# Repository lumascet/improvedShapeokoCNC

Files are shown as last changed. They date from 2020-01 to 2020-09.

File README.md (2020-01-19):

# Improved Shapeoko CNC Mill

:warning: the schematics file is incomplete and has errors which are listed in PATCHNOTES.txt :warning:

This repository contains the config file for g2core as well as the shield schematics for arduino due.

See https://github.com/synthetos/g2 for the g2core project.

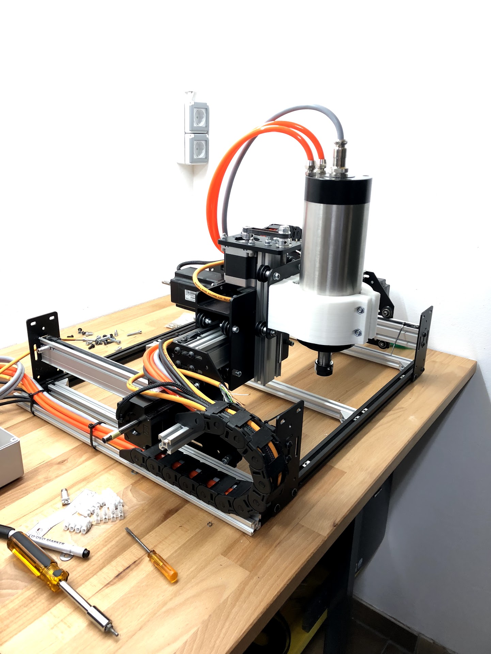
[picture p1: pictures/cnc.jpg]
cnc

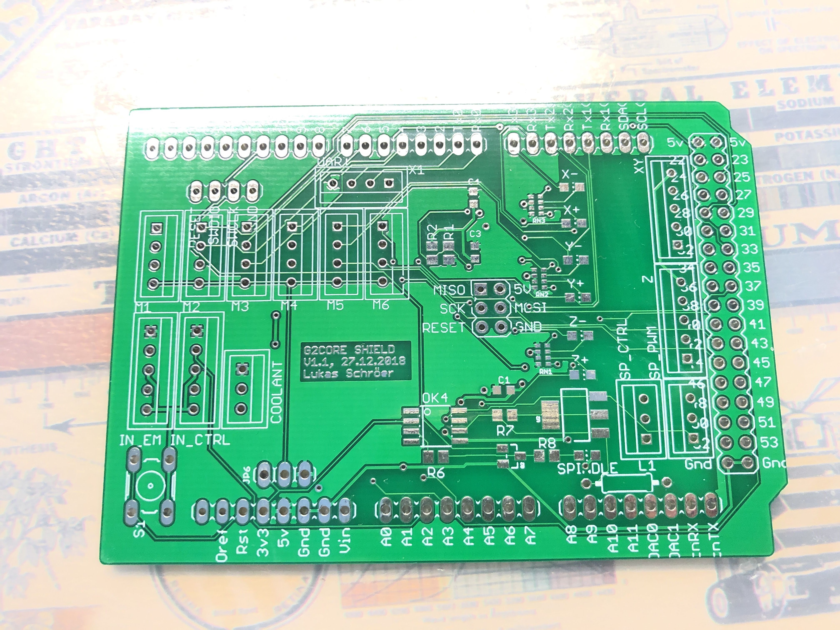
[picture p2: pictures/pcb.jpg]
pcb

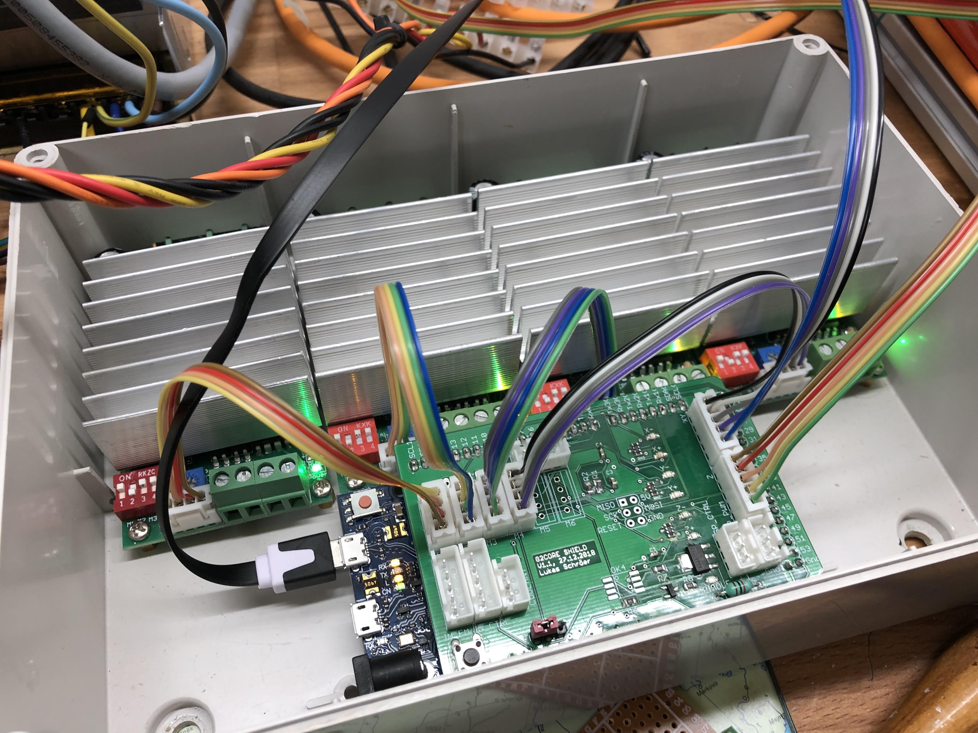
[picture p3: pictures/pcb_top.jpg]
pcb_t

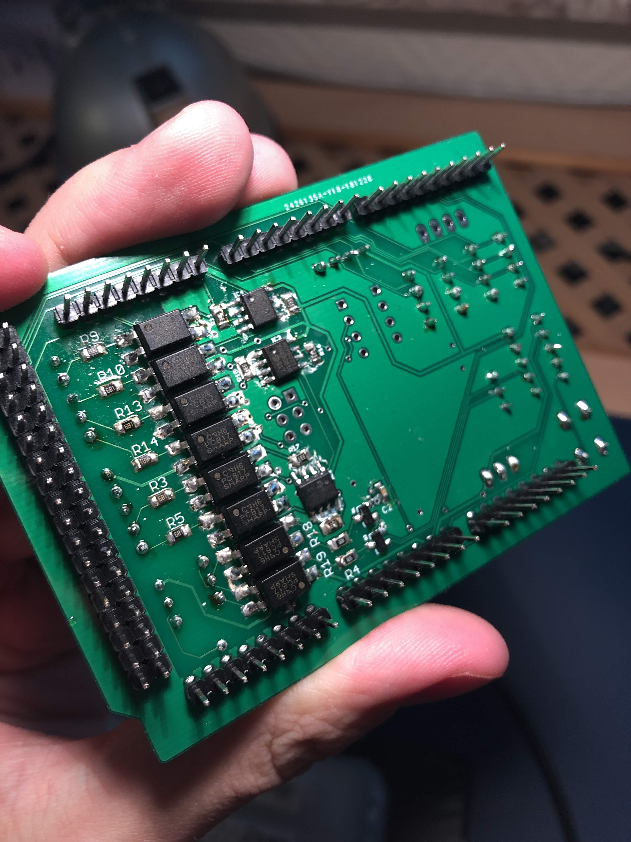
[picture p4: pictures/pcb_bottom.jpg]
pcb_b


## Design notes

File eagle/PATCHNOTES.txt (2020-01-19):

-higher series resistor for optoc. -> powertarget
-after optoc. 3v3 logic -> arduino due not 5V tolerant
-inverting z- axis
-higher series resistor for spindle pwm / otherwise pulse 20mA directly --> failed due to current not possible, modified to 0-5V 10kHz pwm
-switched spindle control @optoc. signals because active low

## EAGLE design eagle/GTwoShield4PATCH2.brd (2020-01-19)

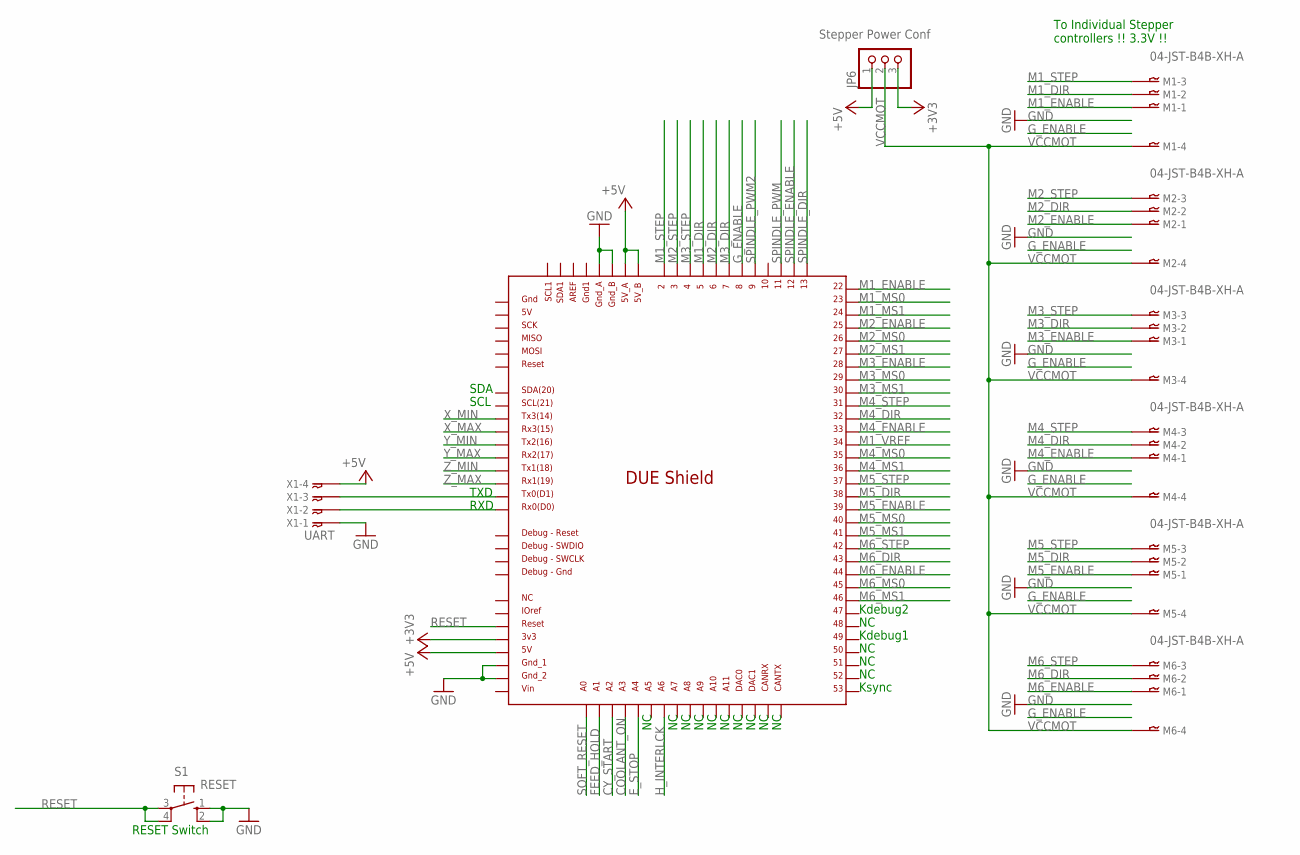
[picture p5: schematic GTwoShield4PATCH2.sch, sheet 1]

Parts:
JP6: Stepper Power Conf; 1X03
M1, M2, M3, M4, M5, M6: 04-JST-B4B-XH-A; B4B-XH
S1: RESET; B3F-10XX
U$1: DUE(NORMAL)
X1: UART; B4B-XH

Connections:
+3V3: JP6.3, U$1.3V3; also elsewhere on the board
+5V: JP6.1, U$1.5V, U$1.5V_A, U$1.5V_B, X1.P$4; also elsewhere on the board
COOLANT_ON: U$1.A3; also elsewhere on the board
CY_START: U$1.A2; also elsewhere on the board
E_STOP: U$1.A4; also elsewhere on the board
FEED_HOLD: U$1.A1; also elsewhere on the board
GND: S1.1 (S), S1.2 (S1), U$1.GND_1, U$1.GND_2, U$1.GND_A, U$1.GND_B, X1.P$1; also elsewhere on the board
G_ENABLE: U$1.8
H_INTERLCK: U$1.A6
M1_DIR: M1.P$2, U$1.5
M1_ENABLE: M1.P$1, U$1.22
M1_MS0: U$1.23
M1_MS1: U$1.24
M1_STEP: M1.P$3, U$1.2
M1_VREF: U$1.34
M2_DIR: M2.P$2, U$1.6
M2_ENABLE: M2.P$1, U$1.25
M2_MS0: U$1.26
M2_MS1: U$1.27
M2_STEP: M2.P$3, U$1.3
M3_DIR: M3.P$2, U$1.7
M3_ENABLE: M3.P$1, U$1.28
M3_MS0: U$1.29
M3_MS1: U$1.30
M3_STEP: M3.P$3, U$1.4
M4_DIR: M4.P$2, U$1.32
M4_ENABLE: M4.P$1, U$1.33
M4_MS0: U$1.35
M4_MS1: U$1.36
M4_STEP: M4.P$3, U$1.31
M5_DIR: M5.P$2, U$1.38
M5_ENABLE: M5.P$1, U$1.39
M5_MS0: U$1.40
M5_MS1: U$1.41
M5_STEP: M5.P$3, U$1.37
M6_DIR: M6.P$2, U$1.43
M6_ENABLE: M6.P$1, U$1.44
M6_MS0: U$1.45
M6_MS1: U$1.46
M6_STEP: M6.P$3, U$1.42
unnamed: U$1.TX0, X1.P$3
unnamed: U$1.RX0, X1.P$2
RESET: S1.3, S1.4 (P1), U$1.RESET
SOFT_RESET: U$1.A0; also elsewhere on the board
SPINDLE_DIR: U$1.13; also elsewhere on the board
SPINDLE_ENABLE: U$1.12; also elsewhere on the board
SPINDLE_PWM: U$1.11; also elsewhere on the board
SPINDLE_PWM2: U$1.9
VCCMOT: JP6.2, M1.P$4, M2.P$4, M3.P$4, M4.P$4, M5.P$4, M6.P$4
X_MAX: U$1.RX3; also elsewhere on the board
X_MIN: U$1.TX3; also elsewhere on the board
Y_MAX: U$1.RX2; also elsewhere on the board
Y_MIN: U$1.TX2; also elsewhere on the board
Z_MAX: U$1.RX1; also elsewhere on the board
Z_MIN: U$1.TX1; also elsewhere on the board

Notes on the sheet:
Kdebug2
Kdebug1
Ksync
SDA
SCL
TXD
RXD
To Individual Stepper controllers !! 3.3V !!
RESET Switch

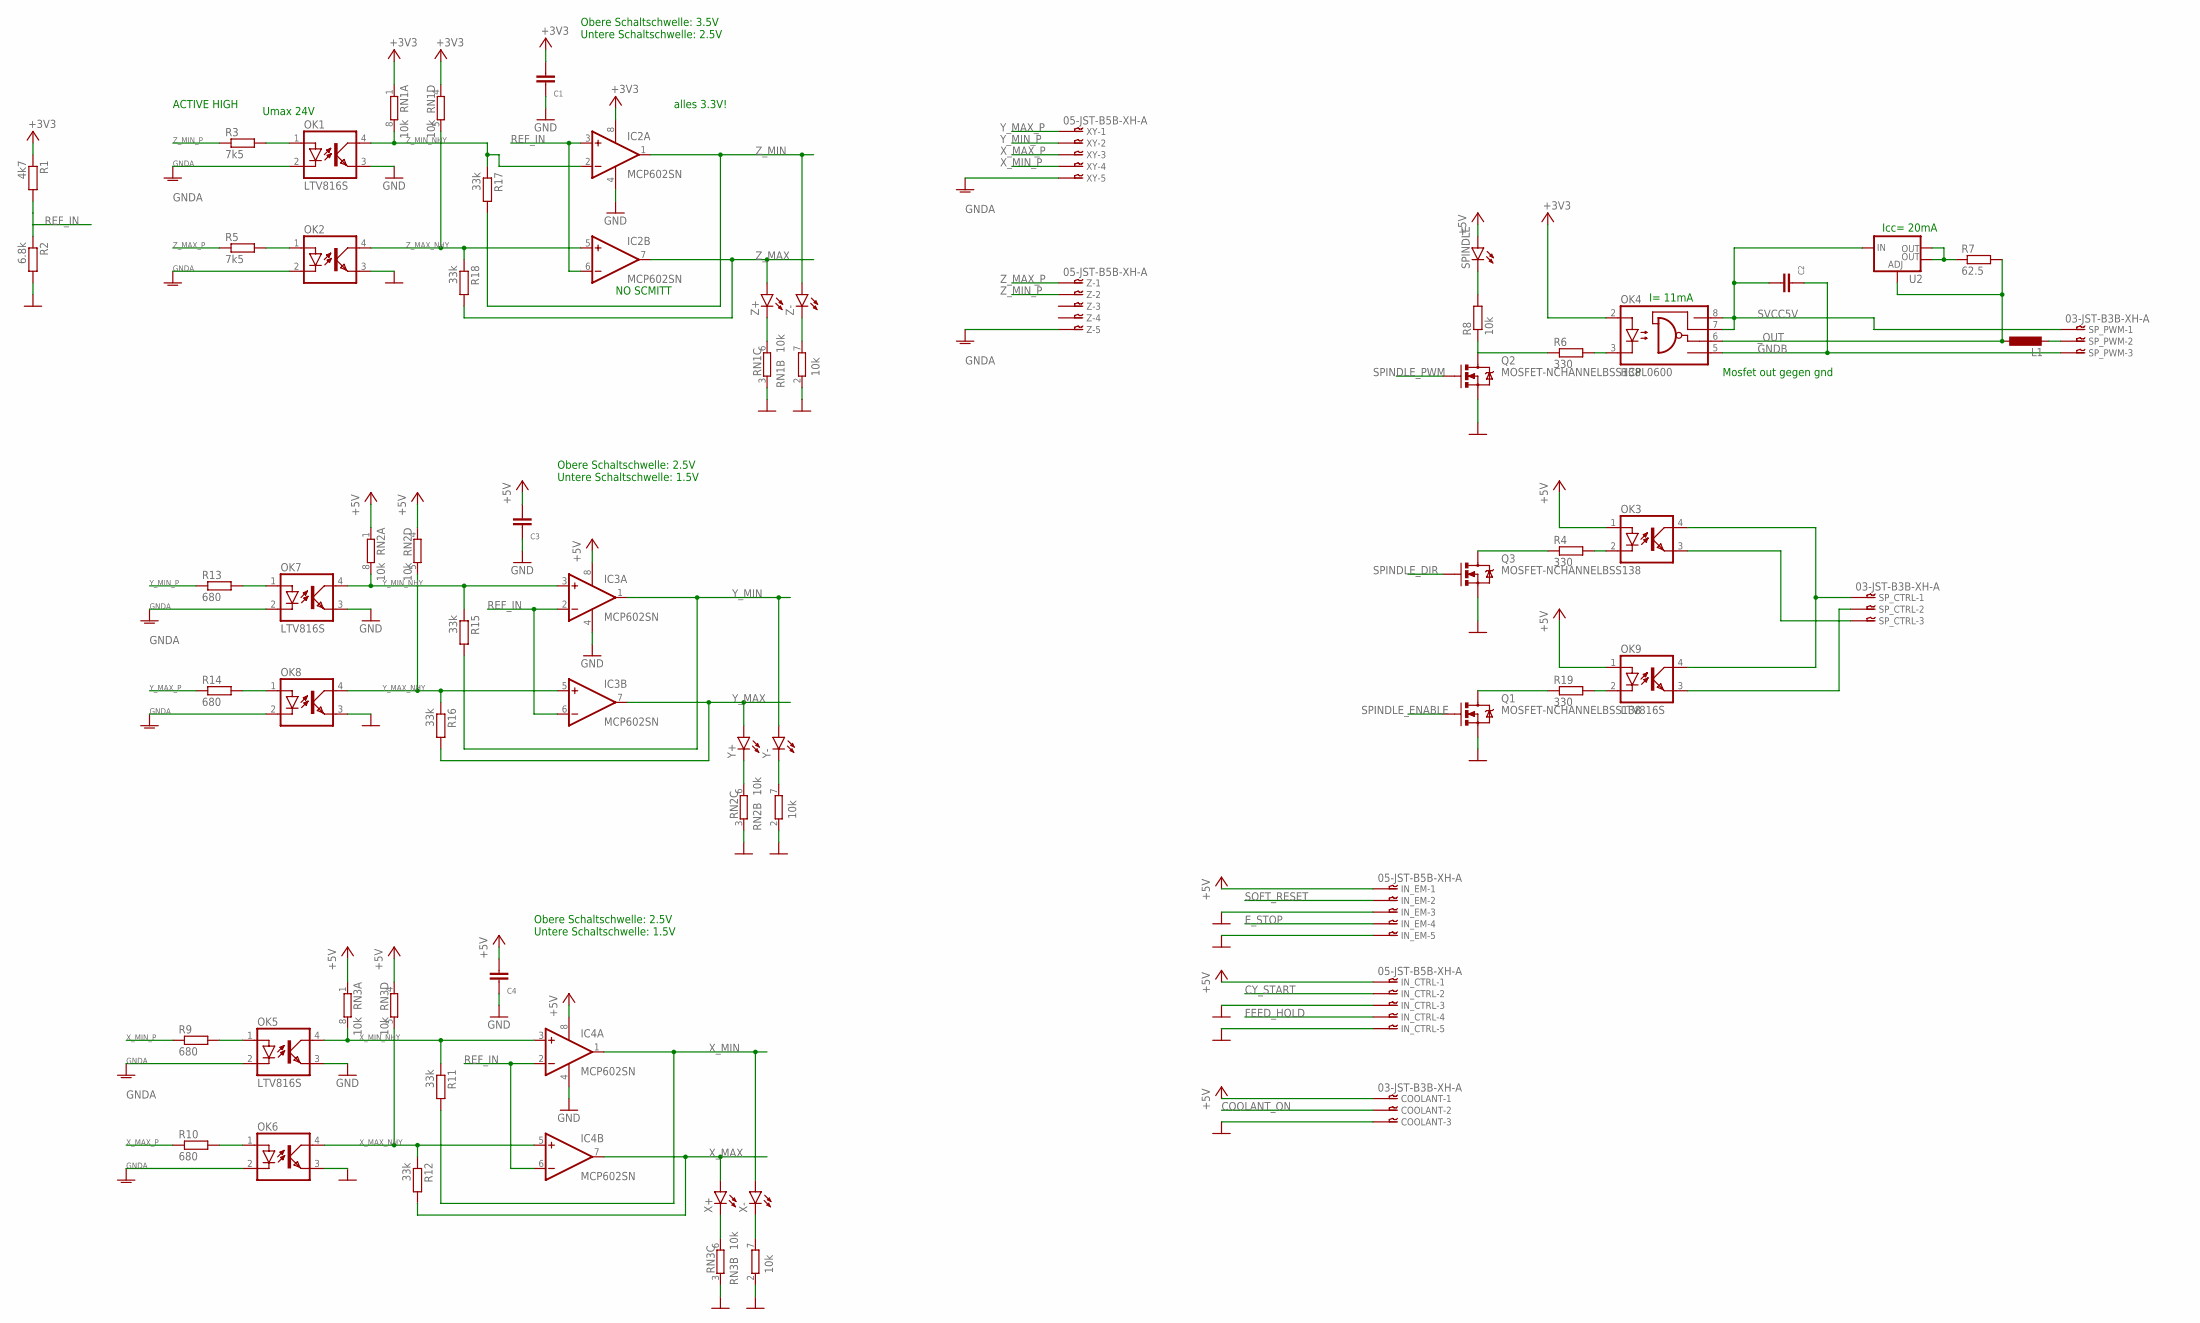
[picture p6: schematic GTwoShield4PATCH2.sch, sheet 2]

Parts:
C1, C2, C3, C4: 100nf; C0603K
COOLANT: 03-JST-B3B-XH-A; B3B-XH
IC2, IC3, IC4: MCP602SN; SO08
IN_CTRL: 05-JST-B5B-XH-A; B5B-XH
IN_EM: 05-JST-B5B-XH-A; B5B-XH
L1: L-EU0207/10; 0207/10
OK1, OK2, OK3, OK5, OK6, OK7, OK8, OK9: LTV816S; DIL4-SMD
OK4: HCPL0600; SOIC08
Q1, Q2, Q3: MOSFET-NCHANNELBSS138; SOT23
R1: 4k7; R0805
R2: 6.8k; R0805
R3, R5: 7k5; R0805
R4, R6, R19: 330; R0805
R7: 62.5; R0805
R8: 10k; R0805
R9, R10, R13, R14: 680; R0805
R11, R12, R15, R16, R17, R18: 33k; R0805
RN1, RN2, RN3: 10k; 0603-ARC
SPINDLE: LEDCHIP-LED0805; CHIP-LED0805
SP_CTRL: 03-JST-B3B-XH-A; B3B-XH
SP_PWM: 03-JST-B3B-XH-A; B3B-XH
U2: V_REG_LM1117SOT223; SOT223
X+: LEDCHIP-LED0805; CHIP-LED0805
X-: LEDCHIP-LED0805; CHIP-LED0805
XY: 05-JST-B5B-XH-A; B5B-XH
Y+: LEDCHIP-LED0805; CHIP-LED0805
Y-: LEDCHIP-LED0805; CHIP-LED0805
Z: 05-JST-B5B-XH-A; B5B-XH
Z+: LEDCHIP-LED0805; CHIP-LED0805
Z-: LEDCHIP-LED0805; CHIP-LED0805

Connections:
+3V3: C1.2, IC2.8 (V+), OK4.2 (A), R1.1, RN1.1, RN1.4 (1); also elsewhere on the board
+5V: C3.2, C4.2, COOLANT.P$1, IC3.8 (V+), IC4.8 (V+), IN_CTRL.P$1, IN_EM.P$1, OK3.1 (A), OK9.1 (A), RN2.1, RN2.4 (1), RN3.1, RN3.4 (1), SPINDLE.A; also elsewhere on the board
COOLANT_ON: COOLANT.P$2; also elsewhere on the board
CY_START: IN_CTRL.P$2; also elsewhere on the board
E_STOP: IN_EM.P$4; also elsewhere on the board
FEED_HOLD: IN_CTRL.P$4; also elsewhere on the board
GND: C1.1, C3.1, C4.1, COOLANT.P$3, IC2.4 (V-), IC3.4 (V-), IC4.4 (V-), IN_CTRL.P$3, IN_CTRL.P$5, IN_EM.P$3, IN_EM.P$5, OK1.3 (EMIT), OK2.3 (EMIT), OK5.3 (EMIT), OK6.3 (EMIT), OK7.3 (EMIT), OK8.3 (EMIT), Q1.2 (S), Q2.2 (S), Q3.2 (S), R2.2, RN1.2 (1), RN1.3 (1), RN2.2 (1), RN2.3 (1), RN3.2 (1), RN3.3 (1); also elsewhere on the board
GNDA: OK1.2 (C), OK2.2 (C), OK5.2 (C), OK6.2 (C), OK7.2 (C), OK8.2 (C), XY.P$5, Z.P$5
GNDB: C2.1, OK4.5 (GND), SP_PWM.P$3
unnamed: RN1.6 (2), Z+.C
unnamed: OK1.1 (A), R3.2
unnamed: OK2.1 (A), R5.2
unnamed: RN1.7 (2), Z-.C
unnamed: OK9.2 (C), R19.2
unnamed: Q1.3 (D), R19.1
unnamed: OK4.3 (C), R6.2
unnamed: OK5.1 (A), R9.2
unnamed: OK6.1 (A), R10.2
unnamed: OK7.1 (A), R13.2
unnamed: OK8.1 (A), R14.2
unnamed: RN2.6 (2), Y+.C
unnamed: RN2.7 (2), Y-.C
unnamed: RN3.6 (2), X+.C
unnamed: RN3.7 (2), X-.C
unnamed: Q2.3 (D), R6.1, R8.1
unnamed: OK3.3 (EMIT), SP_CTRL.P$3
unnamed: L1.2, SP_PWM.P$2
unnamed: R8.2, SPINDLE.C
unnamed: OK3.2 (C), R4.2
unnamed: Q3.3 (D), R4.1
unnamed: R7.1, U2.2 (OUT), U2.4 (OUT)
unnamed: OK3.4 (COL), OK9.4 (COL), SP_CTRL.P$1
unnamed: OK9.3 (EMIT), SP_CTRL.P$2
REF_IN: IC2.3 (+IN), IC2.6 (-IN), IC3.2 (-IN), IC3.6 (-IN), IC4.2 (-IN), IC4.6 (-IN), R1.2, R2.1
SOFT_RESET: IN_EM.P$2; also elsewhere on the board
SPINDLE_DIR: Q3.1 (G); also elsewhere on the board
SPINDLE_ENABLE: Q1.1 (G); also elsewhere on the board
SPINDLE_PWM: Q2.1 (G); also elsewhere on the board
SVCC5V: C2.2, OK4.7 (VE), OK4.8 (VCC), SP_PWM.P$1, U2.3 (IN)
X_MAX: IC4.7 (OUT), R12.2, X+.A; also elsewhere on the board
X_MAX_NHY: IC4.5 (+IN), OK6.4 (COL), R12.1, RN3.5 (2)
X_MAX_P: R10.1, XY.P$3
X_MIN: IC4.1 (OUT), R11.2, X-.A; also elsewhere on the board
X_MIN_NHY: IC4.3 (+IN), OK5.4 (COL), R11.1, RN3.8 (2)
X_MIN_P: R9.1, XY.P$4
Y_MAX: IC3.7 (OUT), R16.2, Y+.A; also elsewhere on the board
Y_MAX_NHY: IC3.5 (+IN), OK8.4 (COL), R16.1, RN2.5 (2)
Y_MAX_P: R14.1, XY.P$1
Y_MIN: IC3.1 (OUT), R15.2, Y-.A; also elsewhere on the board
Y_MIN_NHY: IC3.3 (+IN), OK7.4 (COL), R15.1, RN2.8 (2)
Y_MIN_P: R13.1, XY.P$2
Z_MAX: IC2.7 (OUT), R18.2, Z+.A; also elsewhere on the board
Z_MAX_NHY: IC2.5 (+IN), OK2.4 (COL), R18.1, RN1.5 (2)
Z_MAX_P: R5.1, Z.P$1
Z_MIN: IC2.1 (OUT), R17.2, Z-.A; also elsewhere on the board
Z_MIN_NHY: IC2.2 (-IN), OK1.4 (COL), R17.1, RN1.8 (2)
Z_MIN_P: R3.1, Z.P$2
_OUT: L1.1, OK4.6 (VO), R7.2, U2.1 (ADJ)

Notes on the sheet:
Obere Schaltschwelle: 3.5V Untere Schaltschwelle: 2.5V
Obere Schaltschwelle: 2.5V Untere Schaltschwelle: 1.5V
ACTIVE HIGH
I= 11mA
Umax 24V
Mosfet out gegen gnd
Icc= 20mA
alles 3.3V!
NO SCMITT

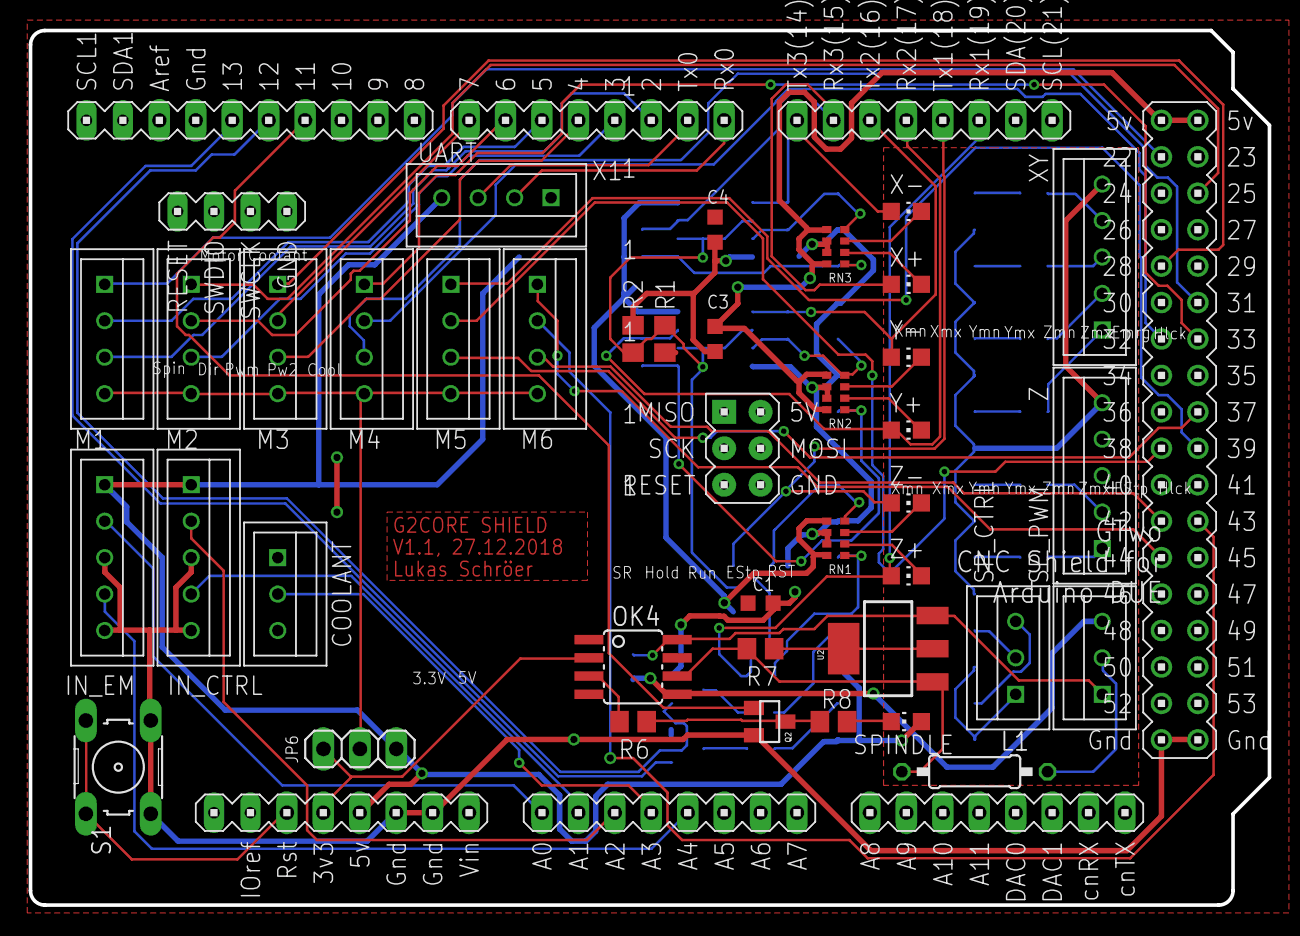
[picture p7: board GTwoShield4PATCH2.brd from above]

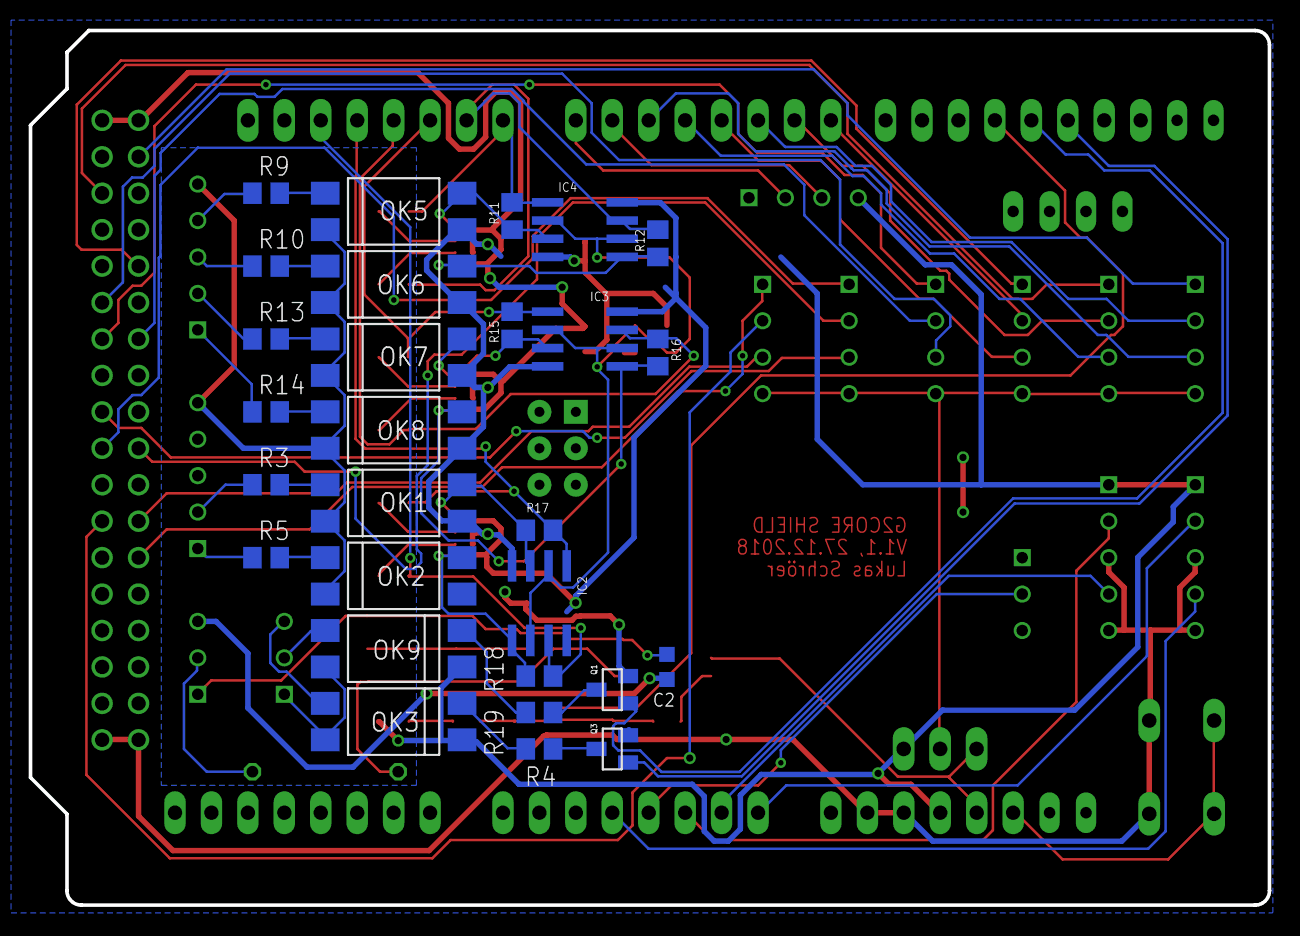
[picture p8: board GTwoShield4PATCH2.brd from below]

Board: 2 copper layers, 86.4 x 61.0 mm, 67 parts (28 on the bottom side), 80 nets.

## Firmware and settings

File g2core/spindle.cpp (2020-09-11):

/*
 * spindle.cpp - canonical machine spindle driver
 * This file is part of the g2core project
 *
 * Copyright (c) 2010 - 2019 Alden S. Hart, Jr.
 *
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
 * As a special exception, you may use this file as part of a software library without
 * restriction. Specifically, if other files instantiate templates or use macros or
 * inline functions from this file, or you compile this file and link it with  other
 * files to produce an executable, this file does not by itself cause the resulting
 * executable to be covered by the GNU General Public License. This exception does not
 * however invalidate any other reasons why the executable file might be covered by the
 * GNU General Public License.
 *
 * THE SOFTWARE IS DISTRIBUTED IN THE HOPE THAT IT WILL BE USEFUL, BUT WITHOUT ANY
 * WARRANTY OF ANY KIND, EXPRESS OR IMPLIED, INCLUDING BUT NOT LIMITED TO THE WARRANTIES
 * OF MERCHANTABILITY, FITNESS FOR A PARTICULAR PURPOSE AND NONINFRINGEMENT. IN NO EVENT
 * SHALL THE AUTHORS OR COPYRIGHT HOLDERS BE LIABLE FOR ANY CLAIM, DAMAGES OR OTHER
 * LIABILITY, WHETHER IN AN ACTION OF CONTRACT, TORT OR OTHERWISE, ARISING FROM, OUT OF
 * OR IN CONNECTION WITH THE SOFTWARE OR THE USE OR OTHER DEALINGS IN THE SOFTWARE.
 */

#include "g2core.h"             // #1 dependency order
#include "config.h"             // #2
#include "canonical_machine.h"  // #3
#include "text_parser.h"        // #4

#include "planner.h"            // for mp_queue_command()
#include "spindle.h"

ToolHead *active_toolhead = nullptr;
bool spindle_pause_enabled = true;

/****************************************************************************************
 * toolhead_for_tool(uint8_t tool) - return the correct toolhead for the tool number
 * spindle_init() - init the spindle / toolhead subsystem
 * spindle_set_toolhead(ToolHead *toolhead) - set the active toolhead
 * spindle_reset() - stop spindle, set speed to zero, and reset values
 */

void spindle_init() {
    // active_toolhead->init();
}

void spindle_set_toolhead(ToolHead *toolhead) {
    active_toolhead = toolhead;
    active_toolhead->reset();
}

void spindle_reset() {
    active_toolhead->reset();
}

/*
 * spindle_stop();
 * spindle_pause();
 * spindle_resume();
 * spindle_set_speed(float speed);                // S parameter - returns STAT_EAGAIN if a command should be queued
 * float  spindle_get_speed();                    // return current speed - in the same units as the S parameter
 * spindle_set_direction(spDirection direction);  // M3/M4/M5 - - returns STAT_EAGAIN if a command should be queued
 * spDirection spindle_get_direction();           // return if any fo M3/M4/M5 are active (actual, not gcode model)
 * bool is_spindle_ready_to_resume(); // if the spindle can resume at this time, return true
 * bool is_spindle_on_or_paused(); // returns if the spindle is on or paused - IOW would it try to resume from feedhold
*/

void spindle_stop() {
    cm->gm.spindle_direction = SPINDLE_OFF;
    cm->gm.spindle_speed = 0;
    if (active_toolhead) {
        active_toolhead->stop();
    }
}
void spindle_pause() {
    if (spindle_pause_enabled && active_toolhead) {
        active_toolhead->pause();
    }
}
void spindle_resume() {
    if (spindle_pause_enabled && active_toolhead) {
        active_toolhead->resume();
    }
}

// A command for placing in the queue, which forces a PTS (plan-to-stop) as well as calls active_toolhead->engage()
static void _exec_spindle_control(float *, bool *) {
    // not really anything to do here - engage() should have just been called
}

stat_t spindle_set_speed(float speed) {
    cm->gm.spindle_speed = speed;

    if (active_toolhead && active_toolhead->set_speed(speed) == true) {
        mp_queue_command(_exec_spindle_control, nullptr, nullptr);
    }

    return (STAT_OK);
}
float spindle_get_speed() {
    if (active_toolhead) { return active_toolhead->get_speed(); }
    return cm->gm.spindle_speed; // if there's not active toolhead, return what the gcode model has
}

stat_t spindle_set_direction(spDirection direction)
{
    cm->gm.spindle_direction = direction;

    if (active_toolhead && active_toolhead->set_direction(direction) == true) {
        mp_queue_command(_exec_spindle_control, nullptr, nullptr);
    }

    return (STAT_OK);
}
spDirection spindle_get_direction() {
    if (active_toolhead) { return active_toolhead->get_direction(); }
    return cm->gm.spindle_direction; // if there's not active toolhead, return what the gcode model has
}

void spindle_engage(const GCodeState_t &gm) {
    if (active_toolhead) { active_toolhead->engage(gm); }
}

bool is_spindle_ready_to_resume() {
    if (active_toolhead) { return active_toolhead->ready_to_resume(); }
    return true;
}
bool is_spindle_on_or_paused() {
    if (active_toolhead) { return active_toolhead->is_on(); }
    return cm->gm.spindle_direction != SPINDLE_OFF;
}
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

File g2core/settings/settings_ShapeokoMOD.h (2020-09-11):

/*
 * settings_shapeoko2.h - Shapeoko2 500mm table
 * This file is part of the g2core project
 *
 * Copyright (c) 2010 - 2018 Alden S. Hart, Jr.
 *
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
 * As a special exception, you may use this file as part of a software library without
 * restriction. Specifically, if other files instantiate templates or use macros or
 * inline functions from this file, or you compile this file and link it with  other
 * files to produce an executable, this file does not by itself cause the resulting
 * executable to be covered by the GNU General Public License. This exception does not
 * however invalidate any other reasons why the executable file might be covered by the
 * GNU General Public License.
 *
 * THE SOFTWARE IS DISTRIBUTED IN THE HOPE THAT IT WILL BE USEFUL, BUT WITHOUT ANY
 * WARRANTY OF ANY KIND, EXPRESS OR IMPLIED, INCLUDING BUT NOT LIMITED TO THE WARRANTIES
 * OF MERCHANTABILITY, FITNESS FOR A PARTICULAR PURPOSE AND NONINFRINGEMENT. IN NO EVENT
 * SHALL THE AUTHORS OR COPYRIGHT HOLDERS BE LIABLE FOR ANY CLAIM, DAMAGES OR OTHER
 * LIABILITY, WHETHER IN AN ACTION OF CONTRACT, TORT OR OTHERWISE, ARISING FROM, OUT OF
 * OR IN CONNECTION WITH THE SOFTWARE OR THE USE OR OTHER DEALINGS IN THE SOFTWARE.
 */

/***********************************************************************/
/**** Shapeoko2 500mm profile ******************************************/
/***********************************************************************/

// ***> NOTE: The init message must be a single line with no CRs or LFs
#define INIT_MESSAGE "Initializing configs to ShapeokoMOD"

//**** GLOBAL / GENERAL SETTINGS ******************************************************

#define JUNCTION_INTEGRATION_TIME   0.75     // cornering - between 0.10 and 2.00 (higher is faster)
#define CHORDAL_TOLERANCE           0.01    // chordal accuracy for arc drawing (in mm)

#define SOFT_LIMIT_ENABLE           1       // 0=off, 1=on
#define HARD_LIMIT_ENABLE           1       // 0=off, 1=on
#define SAFETY_INTERLOCK_ENABLE     1       // 0=off, 1=on

#define SPINDLE_POLARITY            1
#define SPINDLE_ENABLE_POLARITY     1                       // 0=active low, 1=active high
#define SPINDLE_DIR_POLARITY        0                       // 0=clockwise is low, 1=clockwise is high
#define SPINDLE_PAUSE_ON_HOLD       true
#define SPINDLE_SPINUP_DELAY        1.0
#define SPINDLE_SPEED_MIN           0.0
#define SPINDLE_SPEED_MAX           24000.0
#define SPINDLE_SPEED_CHANGE_PER_MS 7.0

#define SPINDLE_ENABLE_OUTPUT_NUMBER 	12
#define SPINDLE_DIRECTION_OUTPUT_NUMBER 13
#define SPINDLE_PWM_NUMBER 		11

#define LASER_MIN_S 0
#define LASER_MAX_S 0
#define LASER_PULSE_DURATION 0
#define LASER_MIN_PPM 0
#define LASER_MAX_PPM 0

#define HAS_LASER 0
#define LASER_TOOL 0
#define BASE_KINEMATICS 1
#define LASER_FIRE_PIN_NUMBER 0

#define P1_PWM_FREQUENCY                10000					// in Hz
#define P1_CW_SPEED_LO                  0		    		// in RPM (arbitrary units)
#define P1_CW_SPEED_HI                  24000
#define P1_CW_PHASE_LO                  0			  	// phase [0..1]
#define P1_CW_PHASE_HI                  1
#define P1_CCW_SPEED_LO                 0
#define P1_CCW_SPEED_HI                 24000
#define P1_CCW_PHASE_LO                 0
#define P1_CCW_PHASE_HI                 1
#define P1_PWM_PHASE_OFF                0.0

#define ESC_BOOT_TIME               5000    // how long the ESC takes to boot, in milliseconds
#define ESC_LOCKOUT_TIME            900     // how long the interlock needs to be engaged before killing power... actually 1s, but be conservative

#define COOLANT_MIST_POLARITY       1       // 0=active low, 1=active high
#define COOLANT_FLOOD_POLARITY      1       // 0=active low, 1=active high
#define COOLANT_PAUSE_ON_HOLD       true

#define FEEDHOLD_Z_LIFT             -1       // mm to lift Z on feedhold, or -1 to go to Z-max
#define PROBE_REPORT_ENABLE         true

#define MANUAL_FEEDRATE_OVERRIDE_ENABLE false
// Switch definitions for interlock & E-stop
#define ENABLE_INTERLOCK_AND_ESTOP
#define INTERLOCK_SWITCH_INPUT          4   // DI4
#define ESTOP_SWITCH_INPUT              2   // DI2
#undef PAUSE_DWELL_TIME
#define PAUSE_DWELL_TIME                1.5 //after unpausing and turning the spindle on, dwell for 1.5s

// Communications and reporting settings

#define USB_SERIAL_PORTS_EXPOSED    1                   // Valid options are 1 or 2, only!

#define COMM_MODE                   AUTO_MODE           // one of: TEXT_MODE, JSON_MODE
#define XIO_ENABLE_FLOW_CONTROL     FLOW_CONTROL_RTS    // FLOW_CONTROL_OFF, FLOW_CONTROL_RTS

#define TEXT_VERBOSITY              TV_VERBOSE          // one of: TV_SILENT, TV_VERBOSE
#define JSON_VERBOSITY              JV_MESSAGES         // one of: JV_SILENT, JV_FOOTER, JV_CONFIGS, JV_MESSAGES, JV_LINENUM, JV_VERBOSE
#define QUEUE_REPORT_VERBOSITY      QR_OFF           // one of: QR_OFF, QR_SINGLE, QR_TRIPLE
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

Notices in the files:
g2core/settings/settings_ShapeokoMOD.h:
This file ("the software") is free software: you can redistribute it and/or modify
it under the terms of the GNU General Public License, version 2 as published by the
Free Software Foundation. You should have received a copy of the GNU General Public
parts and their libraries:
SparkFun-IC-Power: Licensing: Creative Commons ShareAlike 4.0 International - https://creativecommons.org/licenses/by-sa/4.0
